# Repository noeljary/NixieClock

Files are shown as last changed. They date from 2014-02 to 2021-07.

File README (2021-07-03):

# NixieClock

+ contents

- mcu_code:    firmware for nixie clock micro-controller
- schematics:  eagle circuit schematics and pcb designs including pdf versions
- parts_lists: details of all parts required for circuits

+ description

design and implementation data for the nixie clock project, repository includes data relating to the hardware circuit schematic and board design, supplemented by production gerber files and 3d models

code is available for the microcontroller firmware which runs the interface between the clock ic and the nixie tubes and also for the computer backend which will allow for administrative control of the clock

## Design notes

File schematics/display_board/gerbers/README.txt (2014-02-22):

Nixie_Display.cmp - Component Layer (Top Layer)
Nixie_Display.sol - Solder Layer (Bottom Layer)
Nixie_Display.plc - Top Layer Silk Screen
Nixie_Display.pls - Bottom Layer Silk Screen
Nixie_Display.stc - Top Layer Soldermask
Nixie_Display.sts - Bottom Layer Soldermask
Nixie_Display.ncd - Drill File

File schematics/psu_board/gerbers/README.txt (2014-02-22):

Nixie_PSU.cmp - Component Layer (Top Layer)
Nixie_PSU.sol - Solder Layer (Bottom Layer)
Nixie_PSU.plc - Top Layer Silk Screen
Nixie_PSU.pls - Bottom Layer Silk Screen
Nixie_PSU.stc - Top Layer Soldermask
Nixie_PSU.sts - Bottom Layer Soldermask
Nixie_PSU.ncd - Drill File

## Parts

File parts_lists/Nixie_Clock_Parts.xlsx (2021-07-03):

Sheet: Sheet1
Part Type | Value | Quantity | Part Number | Minimum Order | Price/Unit | Price
Transistor | MPSA42 | 12 | 81-0144 | 1 | £0.07 | £0.80
 | IFR820 | 1 | 8648514 | 1 | £0.97 | £0.97
 | 2N7000G MOSFET | 1 | 1459027 | 1 | £0.08 | £0.08
Resistor | Pack | 1 | 13-0270 | 1 | £9.21 | £9.21
 | 5k Cermet Pot | 1 | 68-1945 | 1 | £0.26 | £0.26
Inductor | 33uH 1.5A | 1 | 1768363 | 1 | £1.79 | £1.79
 | 330uH 1A | 1 | 1181648 | 1 | £1.84 | £1.84
Capacitor | 100nF 50v | 10 | 1216445 | 5 | £0.11 | £1.09
 | 100pF 2000V | 6 | 1141797 | 5 | £0.07 | £0.45
 | 680uF 25V E. | 1 | 1800635 | 5 | £0.29 | £1.45
 | 220uF 25V E. | 1 | 9693599 | 5 | £0.11 | £0.54
 | 100uF 25V E. | 1 | 9693580 | 5 | £0.09 | £0.43
 | 470pF 25V | 1 | 1694141 | 1 | £0.02 | £0.02
 | 10uF 250V E. | 1 | 9694013 | 5 | £0.30 | £1.50
 | 1uF Tantalum | 1 | 9708405 | 5 | £0.20 | £1.00
 | 22pF | 2 | 1694229 | 1 | £0.02 | £0.04
 | 10uF Tantalum | 1 | 9708200 | 5 | £0.23 | £1.15
Diode | 1N4001 | 1 | 1843694 | 1 | £0.04 | £0.04
 | 1N5819 | 1 | 1843511 | 1 | £0.02 | £0.02
 | BYV26 | 1 | 5390450 | 1 | £0.25 | £0.25
IC | LM2596-5.0 | 1 | 1150103 | 1 | £3.87 | £3.87
 | LM1117-3.3 | 1 | 1469056 | 1 | £1.12 | £1.12
 | MC34063 | 1 | 82-1088 | 1 | £0.48 | £0.48
 | MCP23008 | 3 | 1439387 | 1 | £0.81 | £2.43
 | DS1307 | 1 | 82-0567 | 1 | £2.98 | £2.98
 | AVR AtMega328P | 1 | 73-4477 | 1 | £3.20 | £3.20
 | Socket DIP 28 | 1 | 22-1726 | 1 | £0.55 | £0.55
 | Socket DIP 18 | 3 | 22-1723 | 1 | £0.53 | £1.60
 | Socket DIP 8 | 2 | 22-1720 | 1 | £0.17 | £0.35
Crystal | 16MHz | 1 | 90-1082 | 1 | £0.23 | £0.23
 | 32.768kHz | 1 | 90-0244 | 1 | £0.27 | £0.27
Misc | Battery Holder CR1220 | 1 | 908642 | 1 | £2.15 | £2.15
 | CR1220 Battery | 1 | 2065165 | 1 | £0.47 | £0.47
 | Vert PCB Mount Switch | 1 | 78-0140 | 1 | £0.37 | £0.37
 | DC Scoket 2.1mm | 1 | 20-0970 | 1 | £0.17 | £0.17
 | Mono 3.5mm Socket | 2 | 20-0138 | 1 | £0.11 | £0.22
 | 40 Pin Transition Connector | 1 | 19-0370 | 1 | £1.18 | £1.18
 | 40 Pin Box Header | 1 | 19-0530 | 1 | £0.97 | £0.97
 |  |  |  |  |  | £45.54

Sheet: Sheet2
Part Type | Value | Quantity | Part Number | Minimum Order | Price/Unit | Price | Total Quantity | Total Price | Number of Clocks
IC | ATMEGA-328PU | 1 |  | 1 | £3.02 | £3.02 | 3 | £9.06 | 3
 | MC34063 | 1 |  | 1 | £0.49 | £0.49 | 3 | £1.48
 | MCP23008 | 3 |  | 10 | £0.56 | £5.60 | 10 | £5.60 | Total Price
 | DS1307 | 1 |  | 1 | £2.81 | £2.81 | 3 | £8.43 | £197.21
 | 24LC128 | 1 |  | 10 | £0.45 | £4.50 | 10 | £4.50
 | LM2596-5.0 | 1 |  | 1 | £3.48 | £3.48 | 3 | £10.44 | Price/Clock
 | LM1117-3.3 | 1 |  | 1 | £1.35 | £1.35 | 3 | £4.05 | £65.74
 | SN74141 | 6 |  | 1 | £0.50 | £3.00 | 18 | £9.00
 | H11D1X | 1 |  | 1 | £0.71 | £0.71 | 3 | £2.13
Transistor | IRF820 | 1 |  | 1 | £0.73 | £0.73 | 3 | £2.19
 | 2N7000 | 2 |  | 1 | £0.09 | £0.17 | 6 | £0.51
Diode | 1N4001 | 1 |  | 1 | £0.04 | £0.04 | 3 | £0.13
 | 1N5819 | 1 |  | 1 | £0.11 | £0.11 | 3 | £0.33
 | BYV26 | 1 |  | 1 | £0.16 | £0.16 | 3 | £0.49
Crystal | 16MHz | 1 |  | 1 | £0.20 | £0.20 | 3 | £0.60
 | 32.768kHz | 1 |  | 1 | £0.27 | £0.27 | 3 | £0.82
Inductor | 330uH | 1 |  | 1 | £1.33 | £1.33 | 3 | £3.99
 | 33uH | 1 |  | 1 | £0.25 | £0.25 | 3 | £0.75
Capacitor | 100nF Polyester Film | 14 |  | 1 | £0.05 | £0.71 | 42 | £2.14
 | 100pF 2kV | 6 |  | 5 | £0.08 | £0.49 | 18 | £1.48
 | 22pF | 2 |  | 1 | £0.04 | £0.07 | 6 | £0.21
 | 10uF Tant. 6.3V 5mm | 2 |  | 5 | £0.23 | £1.15 | 6 | £1.38
 | 1uF Tant. 25V 5mm | 1 |  | 5 | £0.20 | £1.00 | 5 | £1.00
 | 10uF 250V 10-5 | 1 |  | 5 | £0.30 | £1.50 | 5 | £1.50
 | 680uF 16V 8-3.5 | 1 |  | 5 | £0.29 | £1.45 | 5 | £1.45
 | 220uF 16V 7-2.5 | 1 |  | 5 | £0.11 | £0.54 | 5 | £0.54
 | 100uF 16V 5-2 | 1 |  | 5 | £0.09 | £0.43 | 5 | £0.43
 | 470pF 25V | 1 |  | 25 | £0.03 | £0.65 | 25 | £0.65
Resistor | 5k POT | 1 |  | 1 | £0.26 | £0.26 | 3 | £0.79
 | Resistor Pack | 1 |  | 1 | £9.44 | £9.44 | 3 | £28.32
 | 22k x6 Network | 1 |  | 1 | £0.00 | £0.00 | 3 | £0.00
Misc | DC Barrel Jack | 1 |  | 1 | £0.18 | £0.18 | 3 | £0.53
 | WiFly | 1 |  | 1 | £22.41 | £22.41 | 3 | £67.23
 | CR1220 Holder | 1 |  | 1 | £0.00 | £0.00 | 3 | £0.00
 | Tactile Switch | 1 |  | 1 | £0.37 | £0.37 | 3 | £1.11
 | Slide Switch | 1 |  | 1 | £0.00 | £0.00 | 3 | £0.00
 | 2x1 Pin Header | 2 |  | 1 | £0.02 | £0.04 | 6 | £0.13
 | 2x20 Transition Connector | 1 |  | 1 | £1.18 | £1.18 | 3 | £3.54
 | 2x20 Box Header | 1 |  | 1 | £0.97 | £0.97 | 3 | £2.91
 | 3.5mm Stereo Jack | 2 |  | 1 | £0.12 | £0.24 | 6 | £0.72
IC Sockets | 28 Pin | 1 |  | 1 | £0.55 | £0.55 | 3 | £1.65
 | 8 Pin | 3 |  | 1 | £0.17 | £0.51 | 9 | £1.53
 | 18 Pin | 3 |  | 1 | £0.53 | £1.59 | 9 | £4.77
 | 16 Pin | 6 |  | 1 | £0.48 | £2.90 | 18 | £8.71

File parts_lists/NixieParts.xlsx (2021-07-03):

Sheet: PSU Components
Part Number | Value
R1 | 2k5 | Cermet | ±
R2 | 820k |  | ±
R3 | 5k6 |  | ±
R4 | 470k |  | ±
R5,12,19 | 1k |  | ±
R6,7,13,16-18 | 10k |  | ±
R8,9 | 2k2 |  | ±
R10 | 470 |  | ±
R11 | 33 |  | ±
R14-15 | 5k1 |  | ±
C1 | 100u 16V |  | ±
C2,3,9,13-18 | 100n 63V |  | ±
C4 | 470p 25V |  | ±
C5 | 10u 250V |  | ±
C6 | 680u 16V |  | ±
C7 | 220u 16V |  | ±
C8,19 | 10u 6.3V | Tantalum | ±
C10,11 | 22p |  | ±
C12 | 1u 25V | Tantalum | ±
D1 | 1N4001 |  | ±
D2 | BYV26 |  | ±
D3 | 1N914 |  | ±
D4 | 1N5819 |  | ±
IC1 | MC34063 |  | ±
IC2 | LM2596 |  | ±
IC3 | LM1117 |  | ±
IC4 | DS1307 |  | ±
IC5 | 24LC128 |  | ±
IC6 | AtMega 328P |  | ±
IC7-9 | MCP23008 |  | ±
IC10 | WiFly
J1 | DC Jack 2.1mm |  | ±
J2,3 | Stereo Jack 3.5mm |  | ±
JP1 | 2x20 Pin Header |  | ±
JP2 | 1x2 Pin Header |  | ±
L1 | 330u |  | ±
L2 | 33u |  | ±
Q1 | IRF820 |  | ±
Q2 | MPSA92 |  | ±
Q3,4 | 2N7000 |  | ±
X1 | 32.768MHz |  | ±
X2 | 16MHz |  | ±
SW1 | 90Deg PCB Mount |  | ±
SW2 | Slide Switch |  | ±
BT1 | CR1220 Cage
LED1 | 5mm Red |  | ±

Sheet: Display Components
Part Number | Value
N1-6 | IN-14 | ±
IC1-6 | 74141 | ±
OK1 | H11A1
R1 | 470 | ±
R2 | 4k7 | ±
RN1 | 7x22k | ±
C1-6 | 100p 2kV
C7-12 | 100n 63V | ±
JP1 | 2x20 Pin Header | ±
JP2 | 1x2 Pin Header | ±

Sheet: Component Quantities
Part | Quantity | Price | Min. Order | Part Number

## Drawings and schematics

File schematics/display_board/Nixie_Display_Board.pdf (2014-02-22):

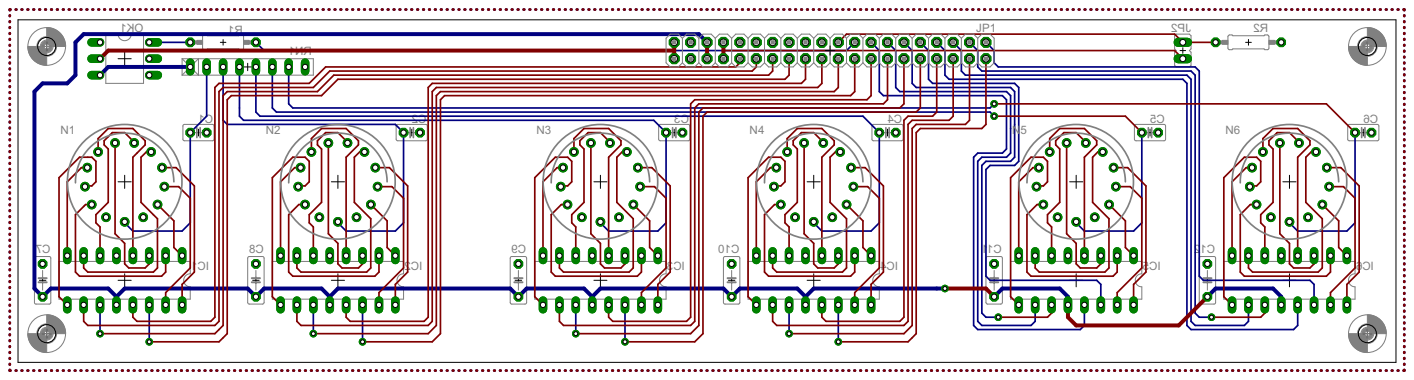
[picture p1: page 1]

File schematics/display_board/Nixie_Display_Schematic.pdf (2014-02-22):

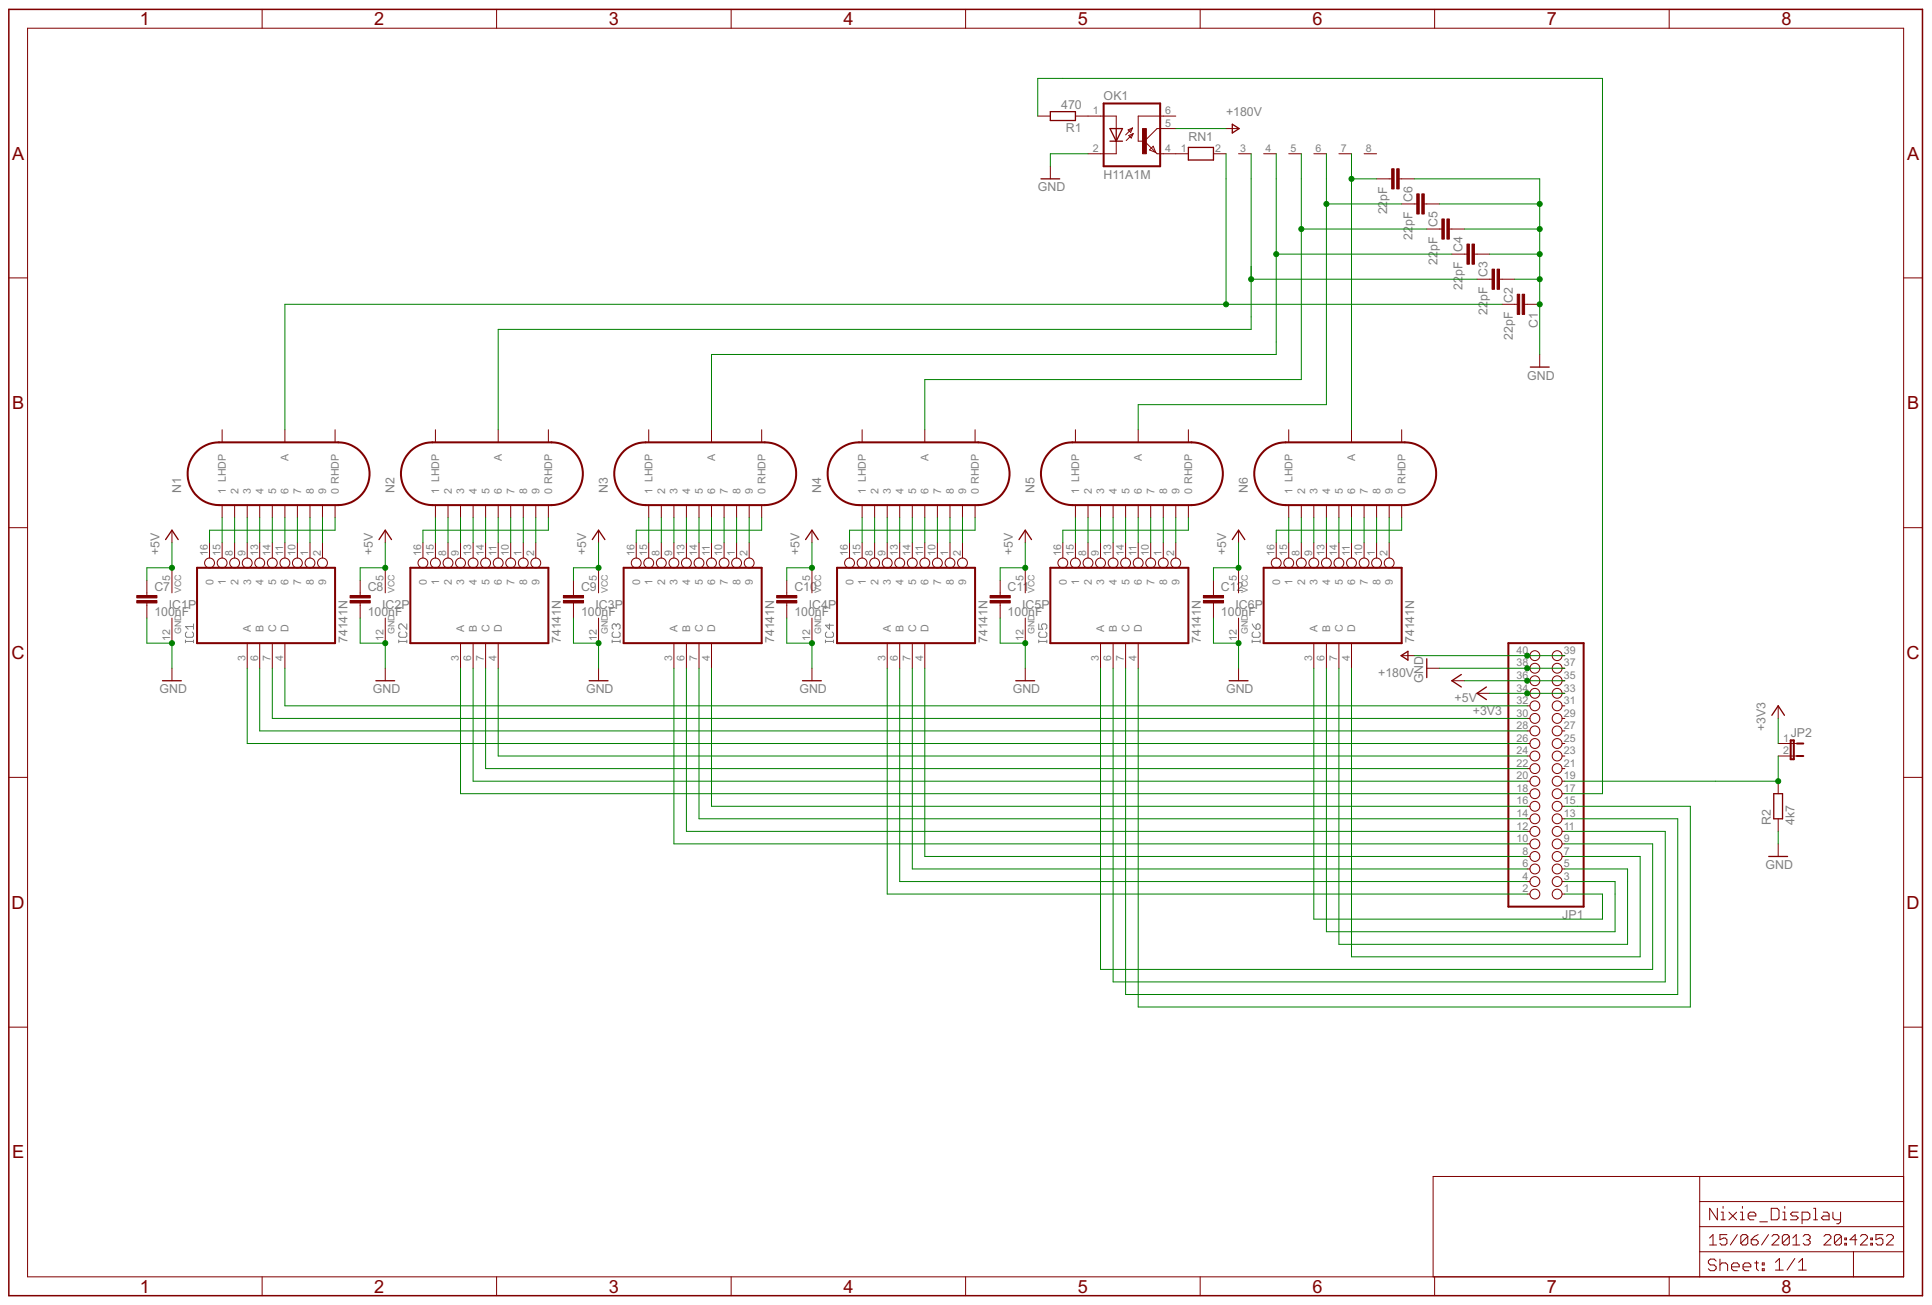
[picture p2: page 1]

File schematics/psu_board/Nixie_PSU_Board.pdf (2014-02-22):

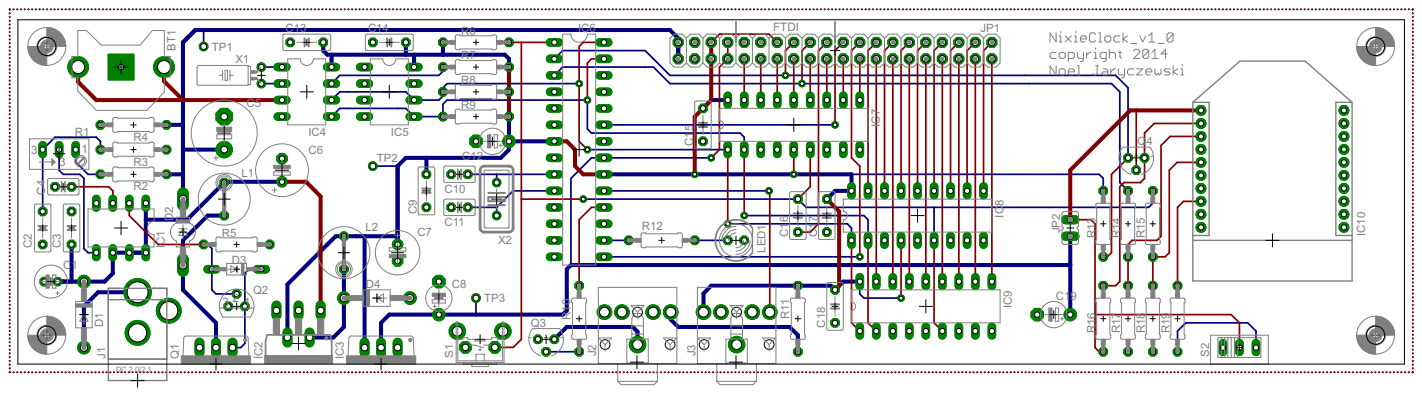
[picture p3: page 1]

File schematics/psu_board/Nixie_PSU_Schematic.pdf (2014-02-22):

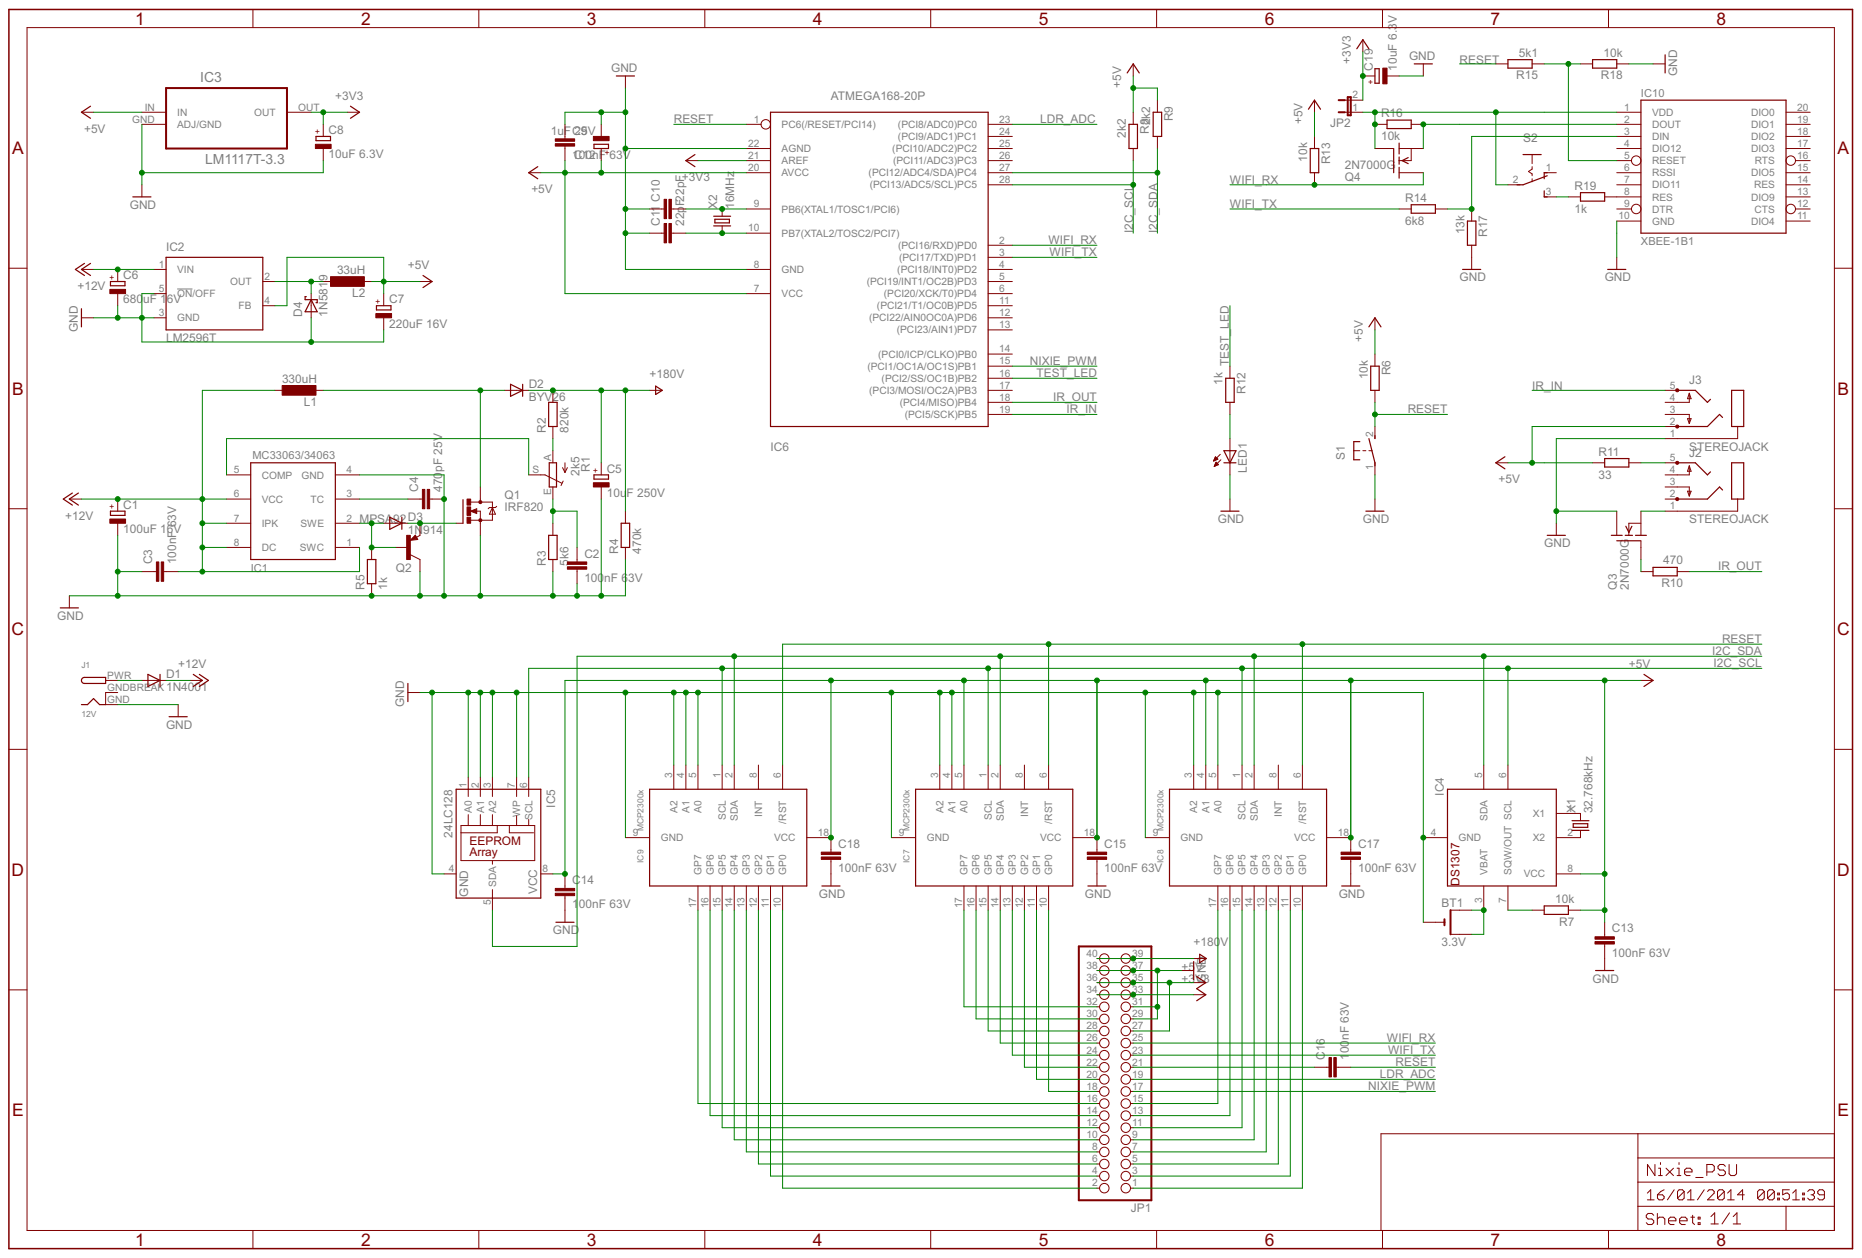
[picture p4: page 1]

30 29
28 27
26 25
24 23 | | | WIFI_TX
22 21 | | | | RESET
20 19 | | | | LDR_ADC
18 17 | | | NIXIE_PWM
16 15
14 13
12 11
10 9
8 7
6 5
4 3
2 1

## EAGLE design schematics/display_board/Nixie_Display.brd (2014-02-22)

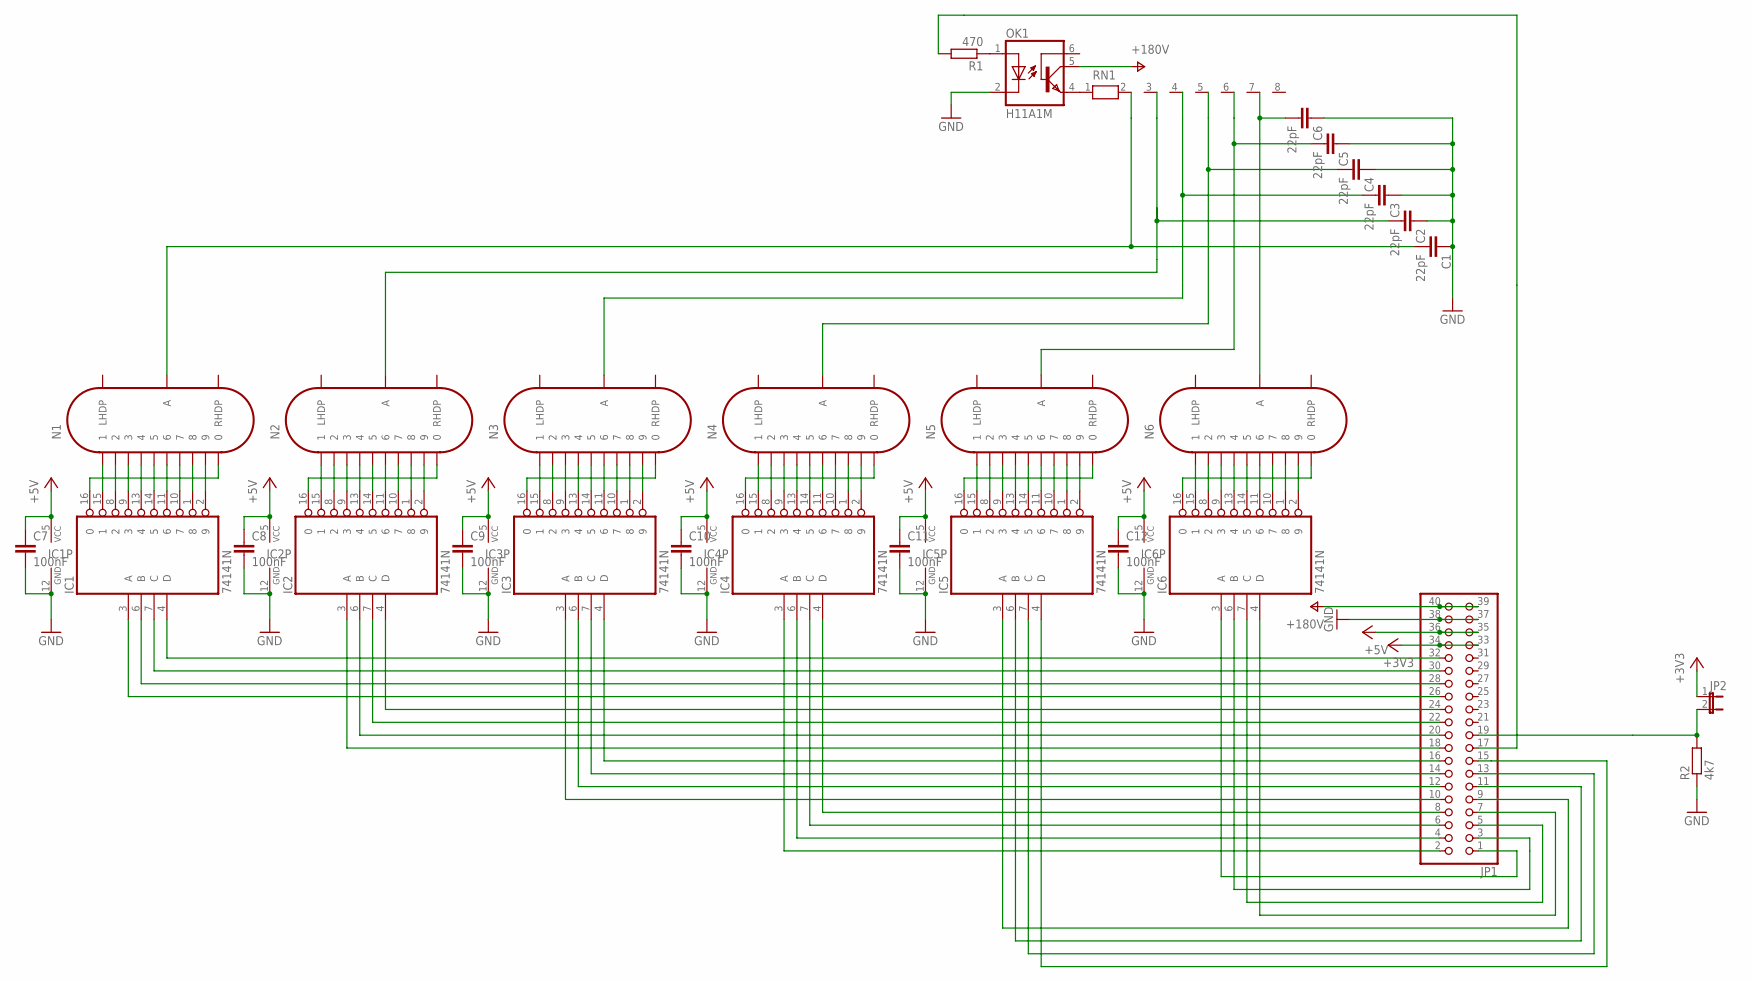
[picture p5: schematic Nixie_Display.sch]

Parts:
C1, C2, C3, C4, C5, C6: 22pF; C025-025X050
C7, C8, C9, C10, C11, C12: 100nF; C050-025X075
IC1, IC2, IC3, IC4, IC5, IC6: 74141N; DIL16
JP1: PINHD-2X20; 2X20
JP2: JP1E; JP1
N1, N2, N3, N4, N5, N6: IN-14
OK1: H11A1M; DIL06
R1: 470; 0207/10
R2: 4k7; 0207/10
RN1: RN07; RN-8

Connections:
+3V3: JP1.33, JP1.34, JP2.1
+5V: C7.1, C8.1, C9.1, C10.1, C11.1, C12.1, IC1.5 (VCC), IC2.5 (VCC), IC3.5 (VCC), IC4.5 (VCC), IC5.5 (VCC), IC6.5 (VCC), JP1.35, JP1.36
GND: C1.1, C2.1, C3.1, C4.1, C5.1, C6.1, C7.2, C8.2, C9.2, C10.2, C11.2, C12.2, IC1.12 (GND), IC2.12 (GND), IC3.12 (GND), IC4.12 (GND), IC5.12 (GND), IC6.12 (GND), JP1.37, JP1.38, OK1.2 (C), R2.1
unnamed: IC1.16 (0), N1.0
unnamed: IC1.15 (1), N1.1
unnamed: IC1.8 (2), N1.2
unnamed: IC1.9 (3), N1.3
unnamed: IC1.13 (4), N1.4
unnamed: IC1.14 (5), N1.5
unnamed: IC1.11 (6), N1.6
unnamed: IC1.10 (7), N1.7
unnamed: IC1.1 (8), N1.8
unnamed: IC1.2 (9), N1.9
unnamed: IC2.16 (0), N2.0
unnamed: IC2.15 (1), N2.1
unnamed: IC2.8 (2), N2.2
unnamed: IC2.9 (3), N2.3
unnamed: IC2.13 (4), N2.4
unnamed: IC2.14 (5), N2.5
unnamed: IC2.11 (6), N2.6
unnamed: IC2.10 (7), N2.7
unnamed: IC2.1 (8), N2.8
unnamed: IC2.2 (9), N2.9
unnamed: IC3.16 (0), N3.0
unnamed: IC3.2 (9), N3.9
unnamed: IC3.1 (8), N3.8
unnamed: IC3.10 (7), N3.7
unnamed: IC3.11 (6), N3.6
unnamed: IC3.14 (5), N3.5
unnamed: IC3.13 (4), N3.4
unnamed: IC3.9 (3), N3.3
unnamed: IC3.8 (2), N3.2
unnamed: IC3.15 (1), N3.1
unnamed: IC4.16 (0), N4.0
unnamed: IC4.2 (9), N4.9
unnamed: IC4.1 (8), N4.8
unnamed: IC4.10 (7), N4.7
unnamed: IC4.11 (6), N4.6
unnamed: IC4.14 (5), N4.5
unnamed: IC4.13 (4), N4.4
unnamed: IC4.9 (3), N4.3
unnamed: IC4.8 (2), N4.2
unnamed: IC4.15 (1), N4.1
unnamed: IC5.16 (0), N5.0
unnamed: IC5.2 (9), N5.9
unnamed: IC5.1 (8), N5.8
unnamed: IC5.10 (7), N5.7
unnamed: IC5.11 (6), N5.6
unnamed: IC5.14 (5), N5.5
unnamed: IC5.13 (4), N5.4
unnamed: IC5.9 (3), N5.3
unnamed: IC5.8 (2), N5.2
unnamed: IC5.15 (1), N5.1
unnamed: IC6.16 (0), N6.0
unnamed: IC6.2 (9), N6.9
unnamed: IC6.1 (8), N6.8
unnamed: IC6.10 (7), N6.7
unnamed: IC6.11 (6), N6.6
unnamed: IC6.14 (5), N6.5
unnamed: IC6.13 (4), N6.4
unnamed: IC6.9 (3), N6.3
unnamed: IC6.8 (2), N6.2
unnamed: IC6.15 (1), N6.1
unnamed: IC6.3 (A), JP1.1
unnamed: IC6.6 (B), JP1.3
unnamed: IC6.7 (C), JP1.5
unnamed: IC6.4 (D), JP1.7
unnamed: IC5.3 (A), JP1.9
unnamed: IC5.6 (B), JP1.11
unnamed: IC5.7 (C), JP1.13
unnamed: IC5.4 (D), JP1.15
unnamed: IC4.3 (A), JP1.2
unnamed: IC4.6 (B), JP1.4
unnamed: IC4.7 (C), JP1.6
unnamed: IC4.4 (D), JP1.8
unnamed: OK1.4 (EMI), RN1.1
unnamed: IC3.3 (A), JP1.10
unnamed: IC3.6 (B), JP1.12
unnamed: C6.2, N6.A, RN1.7
unnamed: IC3.7 (C), JP1.14
unnamed: IC3.4 (D), JP1.16
unnamed: IC2.3 (A), JP1.18
unnamed: IC2.6 (B), JP1.20
unnamed: IC2.7 (C), JP1.22
unnamed: IC2.4 (D), JP1.24
unnamed: IC1.4 (D), JP1.32
unnamed: IC1.7 (C), JP1.30
unnamed: C5.2, N5.A, RN1.6
unnamed: C4.2, N4.A, RN1.5
unnamed: C3.2, N3.A, RN1.4
unnamed: C2.2, N2.A, RN1.3
unnamed: C1.2, N1.A, RN1.2
unnamed: JP1.17, R1.2
unnamed: OK1.1 (A), R1.1
unnamed: IC1.6 (B), JP1.28
unnamed: IC1.3 (A), JP1.26
unnamed: JP1.19, JP2.2, R2.2
V+: JP1.39, JP1.40, OK1.5 (COL)

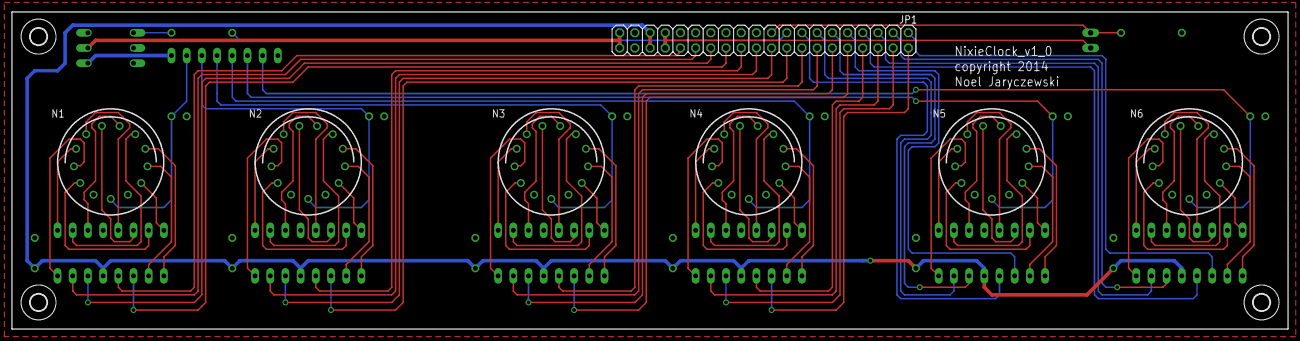
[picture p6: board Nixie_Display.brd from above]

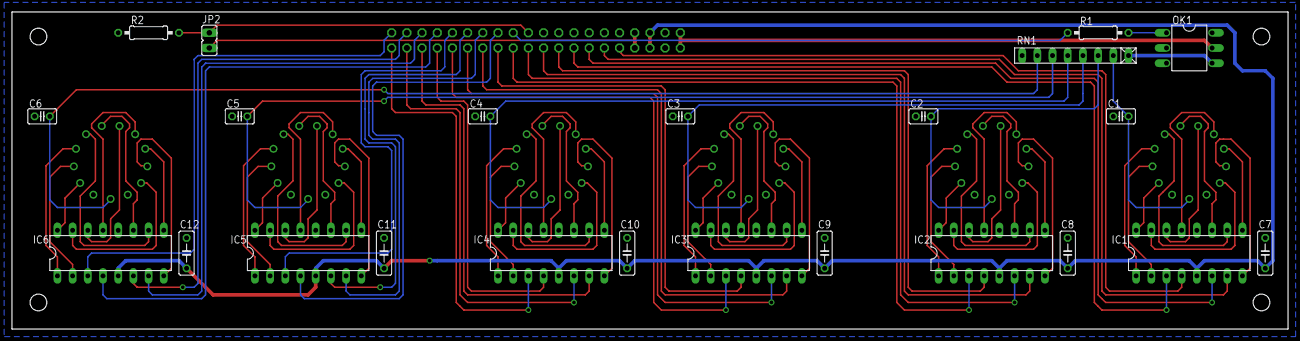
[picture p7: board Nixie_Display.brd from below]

Board: 2 copper layers, 213.3 x 53.0 mm, 34 parts (23 on the bottom side), 98 nets.

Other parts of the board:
U$1, U$2, U$3, U$4: 2,8

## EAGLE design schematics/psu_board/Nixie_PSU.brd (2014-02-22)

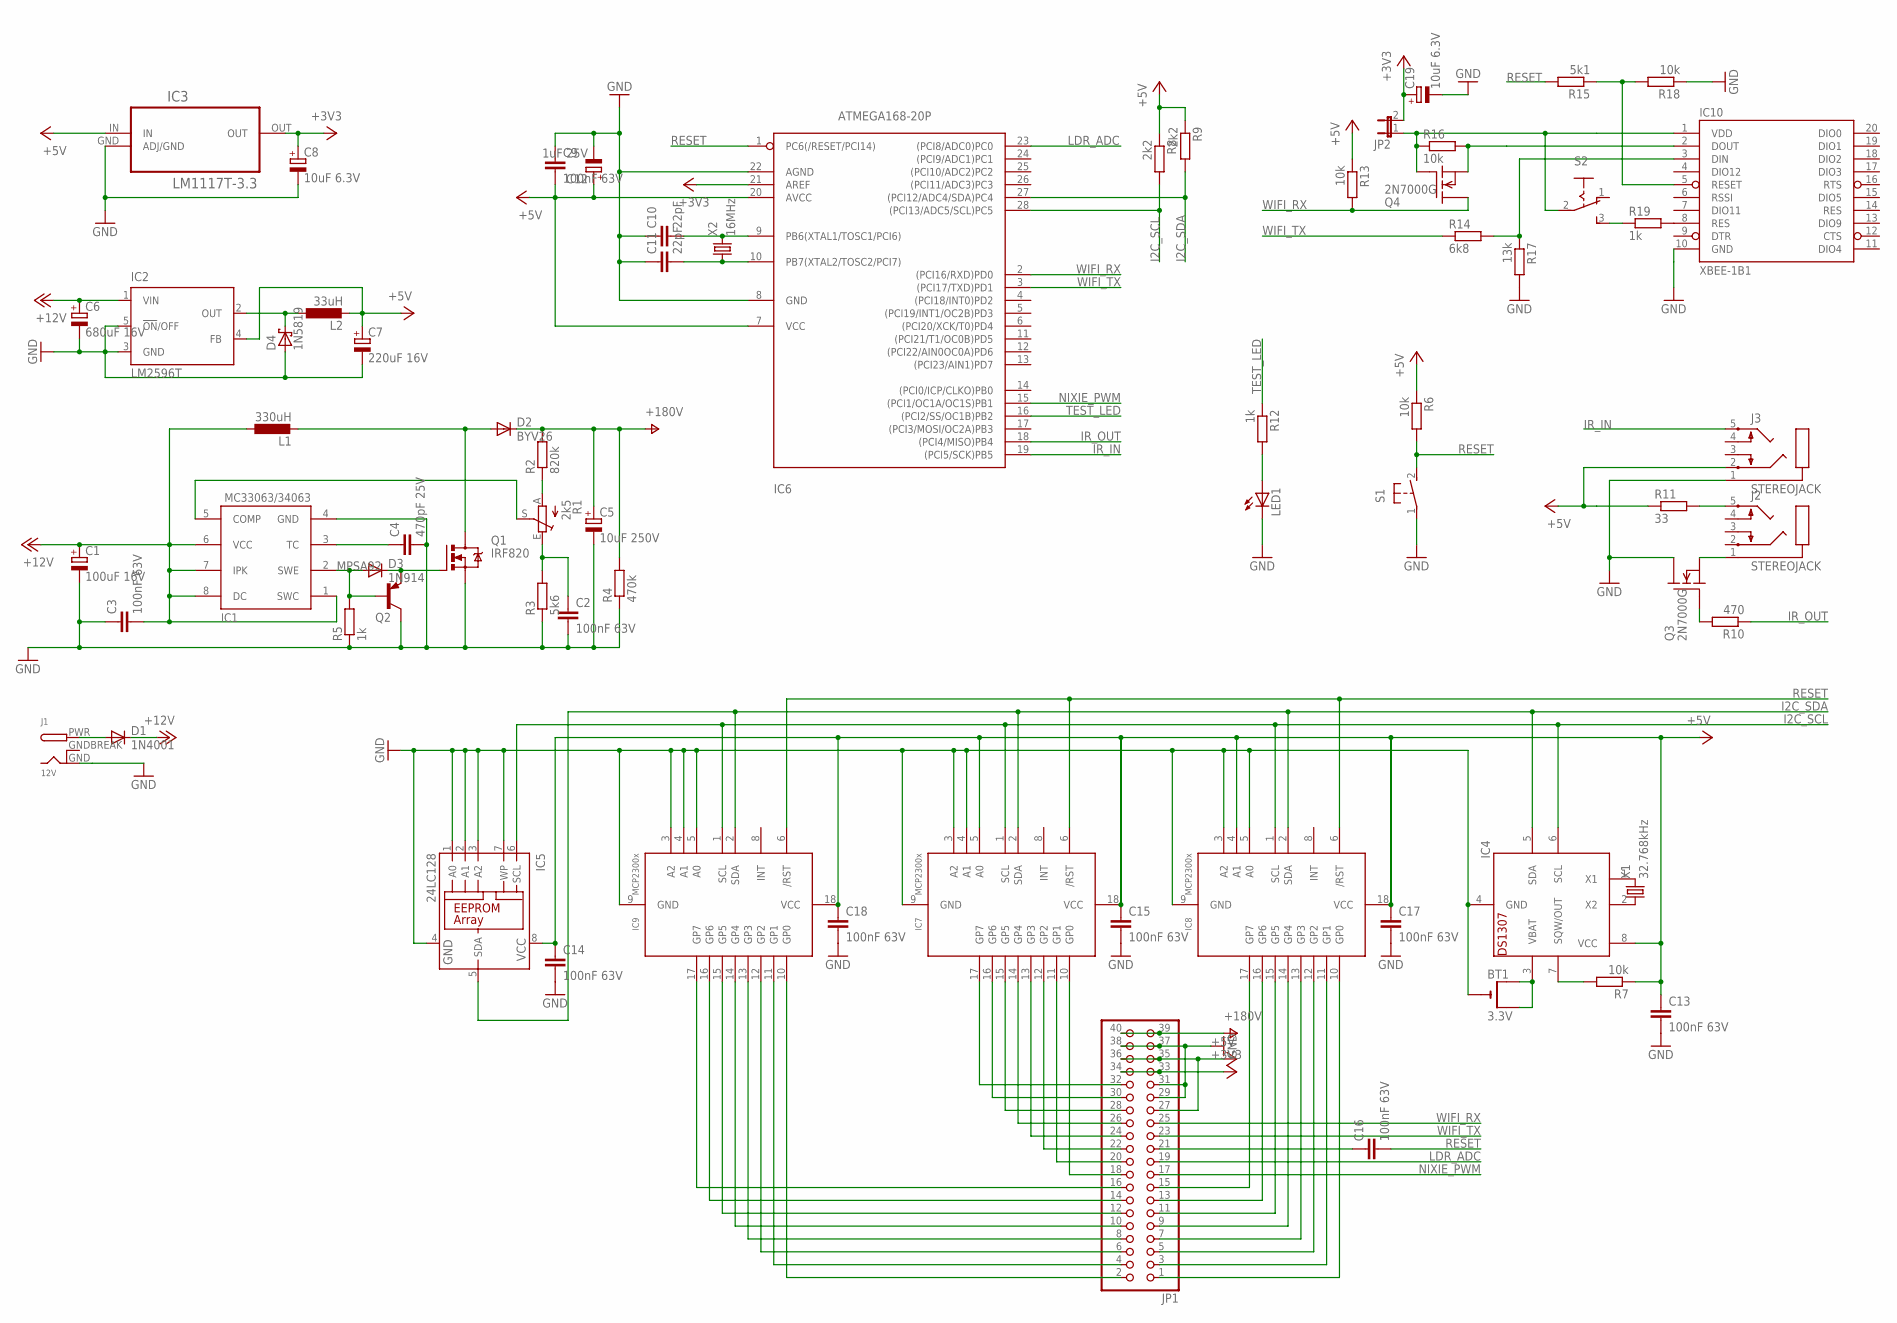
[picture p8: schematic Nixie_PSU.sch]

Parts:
BT1: 3.3V; CR1220-THM
C1: 100uF 16V; E2-5
C2, C3, C9, C13, C14, C15, C16, C17, C18: 100nF 63V; C050-025X075
C4: 470pF 25V; C025-025X050
C5: 10uF 250V; E5-10,5
C6: 680uF 16V; E3,5-8
C7: 220uF 16V; E2,5-7
C8, C19: 10uF 6.3V; E5-4
C10, C11: 22pF; C025-025X050
C12: 1uF 25V; E5-4
D1: 1N4001; DO41-10
D2: BYV26; SOD57-10
D3: 1N914; DO34-7
D4: 1N5819; DO41-10
IC1: MC33063/MC34063P; DIL08
IC2: LM2596T; T05D
IC3: LM1117T-3.3; TO220BV
IC4: DS1307; DIL08
IC5: 24LC128; DIL08
IC6: ATMEGA168-20P; DIL28-3
IC7, IC8, IC9: MCP2300X/P; DIL18
IC10: XBEE-1B1; XBEE-1
J1: 12V; DCJACK_2MM_PTH
J2, J3: STEREOJACK; STX3100
JP1: PINHD-2X20; 2X20
JP2: JP1E; JP1
L1: 330uH; 0207/5V
L2: 33uH; 0207/5V
LED1: LED5MM
Q1: IRF820; TO220BV
Q2: MPSA92; TO92
Q3, Q4: 2N7000G; TO-92
R1: 2k5; RJ9W
R2: 820k; 0207/10
R3: 5k6; 0207/10
R4: 470k; 0207/10
R5, R12, R19: 1k; 0207/10
R6, R7, R13, R16, R18: 10k; 0207/10
R8, R9: 2k2; 0207/10
R10: 470; 0207/10
R11: 33; 0207/10
R14: 6k8; 0207/10
R15: 5k1; 0207/10
R17: 13k; 0207/10
S1: 31-XX; B3F-31XX
S2: M251
X1: 32.768kHz; TC38H
X2: 16MHz; HC18U-V

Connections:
+3V3: C8.+, C19.+, IC3.OUT, IC6.21 (AREF), JP1.33, JP1.34, JP2.2
+5V: C7.+, C9.2, C12.+, C13.1, C14.1, C15.1, C17.1, C18.1, IC2.4 (FB), IC3.IN, IC4.8 (VCC), IC5.8 (VCC), IC6.7 (VCC), IC6.20 (AVCC), IC7.5 (A0), IC7.18 (VCC), IC8.4 (A1), IC8.18 (VCC), IC9.18 (VCC), J3.2, JP1.27, JP1.35, JP1.36, L2.2, R6.1, R7.1, R8.1, R9.1, R11.1, R13.1
+12V: C1.+, C3.2, C6.+, D1.C, IC1.1 (SWC), IC1.6 (VCC), IC1.7 (IPK), IC1.8 (DC), IC2.1 (VIN), L1.1
GND: BT1.-, C1.-, C2.2, C3.1, C4.2, C5.-, C6.-, C7.-, C8.-, C9.1, C10.1, C11.1, C12.-, C13.2, C14.2, C15.2, C17.2, C18.2, C19.-, D4.A, IC1.4 (GND), IC2.3 (GND), IC2.5 (!ON!/OFF), IC3.GND (ADJ/GND), IC4.4 (GND), IC5.1 (A0), IC5.2 (A1), IC5.3 (A2), IC5.4 (GND), IC5.7 (WP), IC6.8 (GND), IC6.22 (AGND), IC7.3 (A2), IC7.4 (A1), IC7.9 (GND), IC8.3 (A2), IC8.5 (A0), IC8.9 (GND), IC9.3 (A2), IC9.4 (A1), IC9.5 (A0), IC9.9 (GND), IC10.10 (GND), J1.GND, J3.1, JP1.29, JP1.31, JP1.37, JP1.38, LED1.K (C), Q1.S, Q2.3 (C), Q3.3 (D), R3.1, R4.1, R5.1, R17.2, R18.1, S1.1
GNDBREAK: J1.GNDBREAK
I2C_SCL: IC4.6 (SCL), IC5.6 (SCL), IC6.28 ((PCI13/ADC5/SCL)PC5), IC7.1 (SCL), IC8.1 (SCL), IC9.1 (SCL), R8.2
I2C_SDA: IC4.5 (SDA), IC5.5 (SDA), IC6.27 ((PCI12/ADC4/SDA)PC4), IC7.2 (SDA), IC8.2 (SDA), IC9.2 (SDA), R9.2
IR_IN: IC6.19 ((PCI5/SCK)PB5), J3.5
IR_OUT: IC6.18 ((PCI4/MISO)PB4), R10.1
LDR_ADC: IC6.23 ((PCI8/ADC0)PC0), JP1.19
unnamed: C4.1, IC1.3 (TC)
unnamed: D3.A, IC1.2 (SWE), Q2.2 (B), R5.2
unnamed: D2.A, L1.2, Q1.D
unnamed: C16.1, JP1.21
unnamed: IC1.5 (COMP), R1.S
unnamed: Q3.2 (G), R10.2
unnamed: J2.1, Q3.1 (S)
unnamed: IC10.1 (VDD), JP2.1, Q4.2 (G), R16.1, S2.2
unnamed: C11.2, IC6.10 (PB7(XTAL2/TOSC2/PCI7)), X2.1
unnamed: C10.2, IC6.9 (PB6(XTAL1/TOSC1/PCI6)), X2.2
unnamed: IC4.1 (X1), X1.2
unnamed: IC4.2 (X2), X1.1
unnamed: BT1.+1 (+), BT1.+2 (+1), IC4.3 (VBAT)
unnamed: IC4.7 (SQW/OUT), R7.2
unnamed: IC9.10 (GP0), JP1.2
unnamed: D4.C, IC2.2 (OUT), L2.1
unnamed: IC9.11 (GP1), JP1.4
unnamed: IC9.12 (GP2), JP1.6
unnamed: IC9.13 (GP3), JP1.8
unnamed: IC9.14 (GP4), JP1.10
unnamed: IC9.15 (GP5), JP1.12
unnamed: IC9.16 (GP6), JP1.14
unnamed: IC9.17 (GP7), JP1.16
unnamed: IC7.10 (GP0), JP1.18
unnamed: IC7.11 (GP1), JP1.20
unnamed: IC7.12 (GP2), JP1.22
unnamed: IC7.13 (GP3), JP1.24
unnamed: IC7.14 (GP4), JP1.26
unnamed: IC7.15 (GP5), JP1.28
unnamed: IC7.16 (GP6), JP1.30
unnamed: IC7.17 (GP7), JP1.32
unnamed: IC8.10 (GP0), JP1.1
unnamed: IC8.11 (GP1), JP1.3
unnamed: IC8.12 (GP2), JP1.5
unnamed: IC8.13 (GP3), JP1.7
unnamed: IC8.14 (GP4), JP1.9
unnamed: IC8.15 (GP5), JP1.11
unnamed: IC8.16 (GP6), JP1.13
unnamed: IC8.17 (GP7), JP1.15
unnamed: R19.1, S2.3 (S)
unnamed: IC10.5 (RESET), R15.1, R18.2
unnamed: D3.C, Q1.G, Q2.1 (E)
unnamed: LED1.A, R12.2
unnamed: J2.5, R11.2
unnamed: IC10.8 (RES), R19.2
unnamed: C2.1, R1.E, R3.2
unnamed: R1.A, R2.1
unnamed: IC10.2 (DOUT), Q4.1 (S), R16.2
unnamed: IC10.3 (DIN), R14.2, R17.1
NIXIE_PWM: IC6.15 ((PCI1/OC1A/OC1S)PB1), JP1.17
PWR: D1.A, J1.PWR
RESET: C16.2, IC6.1 (PC6(/RESET/PCI14)), IC7.6 (/RST), IC8.6 (/RST), IC9.6 (/RST), R6.2, R15.2, S1.2 (S)
TEST_LED: IC6.16 ((PCI2/SS/OC1B)PB2), R12.1
V+: C5.+, D2.C, JP1.39, JP1.40, R2.2, R4.2
WIFI_RX: IC6.2 ((PCI16/RXD)PD0), JP1.25, Q4.3 (D), R13.2
WIFI_TX: IC6.3 ((PCI17/TXD)PD1), JP1.23, R14.1

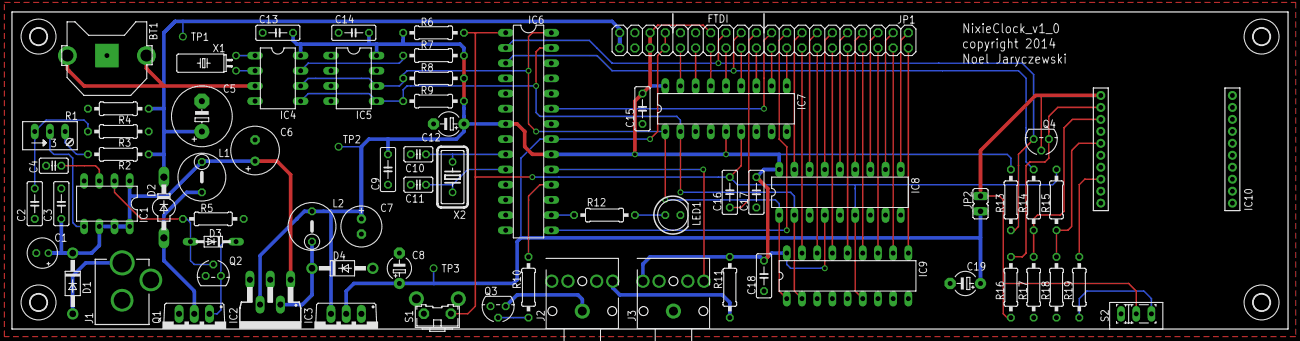
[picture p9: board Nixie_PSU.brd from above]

Board: 2 copper layers, 213.3 x 53.0 mm, 73 parts (0 on the bottom side), 65 nets.

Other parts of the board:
U$1, U$3, U$4, U$5: 2,8

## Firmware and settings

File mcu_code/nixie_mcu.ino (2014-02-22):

#include <Wire.h>
#include <String.h>

#define DS1307_ID 0x68

#define HRS_EXP 0x22
#define MIN_EXP 0x20
#define SEC_EXP 0x21

#define SECONDS_FROM_1970_TO_2000 946684800
#define SECONDS_PER_DAY           86400L

//Pin Definitions
#define CLOCK_PIN  2
#define BRIGHT_PIN 9
#define LED_PIN    10
#define IR_IN_PIN  13
#define IR_OUT_PIN 14

// Store Exact Current Timestamp
byte timestamp[7];

// Update Clock Signal
boolean clockAdv = 0;

// Set LED Toggle Status
boolean ledToggle = 0;

// Nixie Tube Brightness Values
byte bright = 255;
boolean autoBright = 0;

// Serial Command Receive Controls
boolean sOL = 0, eOL = 0, serialUnlocked = 1;
char cmd;
char cmd_arg[25];
byte rx_idx;

void setup() {
	Wire.begin();                                  // Start I2C Connection
	Serial.begin(9600);                            // Start Serial RX/TX Connection

	analogReference(EXTERNAL);                     // Analog Inputs Referenced to 3V3

	i2cWrite(HRS_EXP, 0x00, 1, 0x00);              // Enable Hours Outputs
	i2cWrite(MIN_EXP, 0x00, 1, 0x00);              // Enable Minutes Outputs
	i2cWrite(SEC_EXP, 0x00, 1, 0x00);              // Enable Seconds Outputs
	i2cWrite(DS1307_ID, 0x07, 1, (byte[]) {0x10}); // Enable Clock Timepulse
	
	pinMode(CLOCK_PIN, INPUT);                     // Setup Interrupt Pin
	attachInterrupt(0, clockInterrupt, FALLING);   // Attach Interrupt Function

	pinMode(BRIGHT_PIN, OUTPUT);                   // Setup Brightness Pin
	analogWrite(BRIGHT_PIN, bright);               // Start with Full Brightness
	
	pinMode(LED_PIN, OUTPUT);                      // Setup LED Pin
}

void loop() {
	// If Auto Brightness enabled in EEPROM or runtime
	if(autoBright) {
		analogWrite(BRIGHT_PIN, (bright = map(constrain(analogRead(A0), 300, 850), 300, 850, 25, 255)));
	}

	// If 1Hz signal received from DS1307
	if(clockAdv) {
		// Update Tubes with Time
		updateClock();

		// Toggle LED ON/OFF
		ledToggle = !ledToggle;
		digitalWrite(LED_PIN, ledToggle);

		clockAdv = 0;
	}

	// If Serial Command Received (Not from WiFly)
	if(sOL && eOL) {
		processSerialCommand();
	}
}

// Declare Software Reset Function
void(* resetClock) (void) = 0;

void serialEvent() {
	// Only receive if not already processing request
	if(serialUnlocked) {
		while(Serial.available ()) {
			char rx_char = Serial.read();

			// Receive Serial Commands in {} notation 
			if(rx_char == '{') {
				sOL = 1;
				continue;
			} else if(rx_char == '}') {
				cmd_arg[rx_idx] = '\0';
				Serial.flush();
				eOL = 1;
				break;
			}

			if(sOL && !eOL) {
				if(cmd == '\0') {
					cmd = rx_char;
				} else {
					cmd_arg[rx_idx++] = rx_char;
					cmd_arg[rx_idx]   = '\0';
				}
			}
		}
	}
}



void processSerialCommand() {
	// Block Serial Event Method
	serialUnlocked = 0;

	returnSerialResp("ACK", cmd_arg);
	delay(50);

	switch(cmd) {
		case 'c':
			// Cycle Cathodes to avoid poisoning through unuse
			antiCathodePoison(atoi(cmd_arg));
		break;

		case 'h':
			// Manually set Hours Digits
			updateDigitPair(HRS_EXP, atoi(cmd_arg));
		break;

		case 'l':
			// Enable/Disable AutoBrightness & Set Levels
			char resp[8];
			byte old_bright;
			old_bright = bright;
			bright = constrain(atoi(cmd_arg), 0, 255);

			if(bright == 0) {
				enableAutoBright();
			} else {
				disableAutoBright(bright);
				sprintf(resp, "%d|%d", (byte) ((old_bright / 255.0) * 100), (byte) ((bright / 255.0) * 100));
			}

			returnSerialResp("RSP", resp);
		break;

		case 'm':
			// Manually set Minutes Digits
			updateDigitPair(MIN_EXP, atoi(cmd_arg));
		break;

		case 's':
			// Manually set Seconds Digits
			updateDigitPair(SEC_EXP, atoi(cmd_arg));
		break;

		case 't':
			// Force Time Update
			if(rx_idx > 0) {
				// Update from Computer Value
				setTime(atol(cmd_arg));
				returnSerialResp("RSP", cmd_arg);
			} else {
				// Update from WiFly NTP
				unsigned long ts = setTime();
				char resp[12];
				sprintf(resp, "%lu", ts);
				if(ts > 0) {
					returnSerialResp("RSP", resp);
				} else {
					returnSerialResp("RSP", "ERR");
				}
			}
		break; 
	}

	// Enable Serial Event Method
	returnSerialResp("AOK", cmd_arg);

	// Clear all Serial Data as now processed
	sOL = 0;
	eOL = 0;
	rx_idx = 0;
	cmd = '\0';
	serialUnlocked = 1;
}

void returnSerialResp(char hdr[4], char *val) {
	Serial.print("{");
	Serial.print(hdr);
	Serial.print("-");
	Serial.print(cmd);
	if(strcmp(val, "") != 0) {
		Serial.print("-");
		Serial.print(val);
	}
	Serial.print("}\n");
}

void clockInterrupt() {
	// Signal main loop to advance clock from interrupt
	clockAdv = true;
}

boolean connectWiFly() {
	Serial.print("$$$");
	return Serial.find("CMD");
}

boolean disconnectWiFly() {
	Serial.print("exit\r");
	return Serial.find("EXIT");
}

unsigned long setTime() {
	unsigned long ts = 0;

	// Force NTP update on WiFly
	if(connectWiFly()) {
		Serial.print("time\r");
		if(Serial.find("time")) {
			char line[20];
			byte line_pos = 0;

			Serial.flush();
			Serial.print("show t t\r");

			delay(150);

			while(Serial.available()) {
				line[line_pos++] = Serial.read();
				line[line_pos]   = '\0';

				if(line[line_pos - 1] == '\n') {
					if(line_pos > 2 && line[0] == 'R' && line[1] == 'T' && line[2] == 'C') {
						break;
					} else {
						line[0]  = '\0';
						line_pos = 0;
					}
				}
			}

			sscanf(line, "RTC=%lu", &ts);
		}

		if(!disconnectWiFly()) {
			resetClock();
		}
	}


	// Call overloaded setTime function with timestamp
	if(ts > 0) {
		setTime(ts);
	}

	return ts;
}

void setTime(unsigned long t) {
	// Set DS1307 with time data
	int yOff, m, d, hh, mm, ss, days, leap;
	const byte daysInMonth[] = {31, 28, 31, 30, 31, 30, 31, 31, 30, 31, 30, 31};

	// Get Time Since 2000
	t -= SECONDS_FROM_1970_TO_2000;

	// Calculate Seconds, Minutes, Hours into Day
	ss = t % 60;
	t /= 60;
	mm = t % 60;
	t /= 60;
	hh = t % 24;

	// Calculate Number of Days Since 2000
	days = t / 24;

	// Breakdown number of Years accounting for Leaps
	for(yOff = 0; ; ++yOff) {
		leap = yOff % 4 == 0;
		if(days < 365 + leap) {
			 break; 
		}
		days -= 365 + leap;
	}

	// Breakdown for Months
	for(m = 1; ; ++m) {
		 byte daysPerMonth = daysInMonth[m - 1];

		 if(leap && m == 2) {
			 ++daysPerMonth;
		 }

		 if(days < daysPerMonth) {
			 break;
		 }

		 days -= daysPerMonth;
	}

	d = days + 1;

	// Begin Update DS1307
	stopClock();

	byte timeData[] = {(dec2bcd(ss) | 0x80), dec2bcd(mm), (dec2bcd(hh) & 0x3f), dec2bcd(0), dec2bcd(d), dec2bcd(m), dec2bcd(yOff)};
	i2cWrite(DS1307_ID, 0x00, 7, timeData);

	startClock();
	// End Update DS1307
}

void stopClock() {
	byte ss[1];
	i2cRead(DS1307_ID, 0x00, 1, ss);
	i2cWrite(DS1307_ID, 0x00, 1, (byte []) {ss[0] | 0x80});
}

void startClock() {
	byte ss[1];
	i2cRead(DS1307_ID, 0x00, 1, ss);
	i2cWrite(DS1307_ID, 0x00, 1, (byte []) {ss[0] & 0x7f});
}

void updateClock() {
	i2cRead(DS1307_ID, 0x00, 7, timestamp);                     // Request Timestamp
	updateDigitPair(SEC_EXP, bcd2dec(timestamp[0] & 0x7f));     // Set Seconds
	updateDigitPair(MIN_EXP, bcd2dec(timestamp[1]));            // Set Minutes
	updateDigitPair(HRS_EXP, bcd2dec(timestamp[2]));            // Set Hours
}

void updateDigitPair(byte addr, byte timeVal) {
	byte digitPair[] = {(dec2bcd(numConvert(timeVal % 10)) << 4) + dec2bcd(numConvert((byte) timeVal / 10))};
	i2cWrite(addr, 0x09, 1,digitPair);
}

void antiCathodePoison(int count) {
	for(int i = 0; i < count; i++) {
		for(byte j = 0; j < 10; j++) {
			delay(75);
			byte digitPair[] = {(dec2bcd(numConvert(j)) << 4) + dec2bcd(numConvert(j))};
			i2cWrite(HRS_EXP, 0x09, 1, digitPair);
			i2cWrite(MIN_EXP, 0x09, 1, digitPair);
			i2cWrite(SEC_EXP, 0x09, 1, digitPair);
		}
	}
}

byte numConvert(byte in) {
	// Pin Mapping Function for incorrect routing
	return (11 - in) % 10;
}

boolean enableAutoBright() {
	autoBright = 1;
}

boolean disableAutoBright(byte bright) {
	autoBright = 0;
	analogWrite(BRIGHT_PIN, bright);
}

void i2cWrite(byte addr, byte reg, byte num, byte val[]) {
	Wire.beginTransmission(addr);
	Wire.write(reg);

	for(byte i = 0; i < num; i++) {
		Wire.write(val[i]); 
	}

	Wire.endTransmission();
}

void i2cRead(byte addr, byte reg, byte num, byte res[]) {
	Wire.beginTransmission(addr);
	Wire.write(reg);
	Wire.endTransmission();
	Wire.requestFrom(addr, num);

	for(byte i = 0; i < num; i++) {
		 res[i] = Wire.read();
	}
}

void eepromWrite(byte deviceaddress, unsigned int eeaddress, byte data) {
    Wire.beginTransmission(deviceaddress);
    Wire.write((int)(eeaddress >> 8)); // MSB
    Wire.write((int)(eeaddress & 0xFF)); // LSB
    Wire.write(data);
    Wire.endTransmission();
    delay(5);
}

byte eepromRead(byte deviceaddress, int eeaddress) {
    byte rdata = 0xFF;
    Wire.beginTransmission(deviceaddress);
    Wire.write((int) (eeaddress >> 8)); // MSB
    Wire.write((int) (eeaddress & 0xFF)); // LSB
    Wire.endTransmission();
    Wire.requestFrom((int) deviceaddress, 1);
    if (Wire.available()) rdata = Wire.read();
    return rdata;
}

uint8_t dec2bcd(uint8_t num) {
	return ((num / 10 * 16) + (num % 10));
}

uint8_t bcd2dec(uint8_t num) {
	return ((num / 16 * 10) + (num % 16));
}

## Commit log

2014-02-22 Complete circuit schematics, board designs, pdf versions, gerber files and 3d model
    [Nixie_Display.brd, Nixie_Display.sch, Nixie_PSU.brd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]
2021-07-03 Add Parts List
    [NixieParts.xlsx, Nixie_Clock_Parts.xlsx]

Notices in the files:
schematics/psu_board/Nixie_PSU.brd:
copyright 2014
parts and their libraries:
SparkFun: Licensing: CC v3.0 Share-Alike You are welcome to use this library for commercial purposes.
